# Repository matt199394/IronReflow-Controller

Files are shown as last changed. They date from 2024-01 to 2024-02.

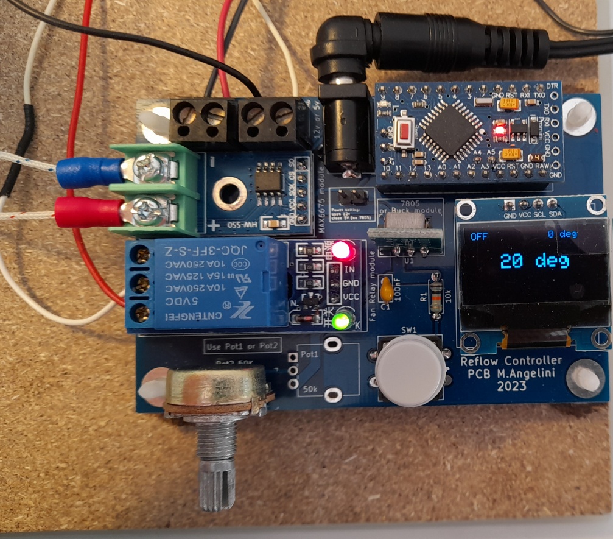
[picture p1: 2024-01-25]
assembled_pcb.jpg

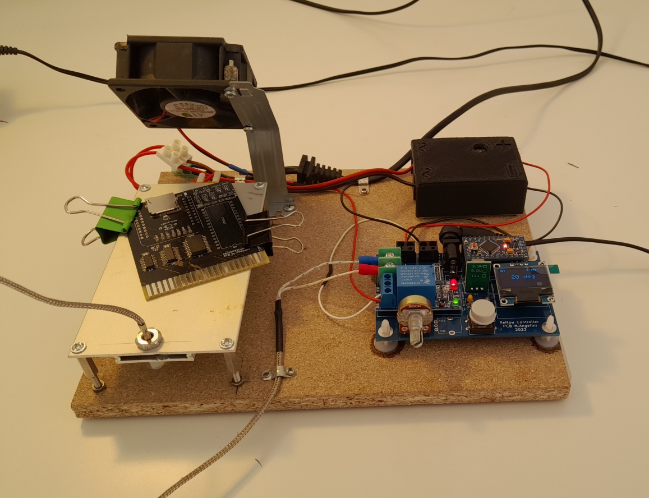
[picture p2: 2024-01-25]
final_result.jpg

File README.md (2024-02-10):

Iron Relow station Aka Soldering/Desoldering SMD Station

Brilliant project find on youtube at https://www.youtube.com/watch?v=2hhL1sXg254&t=1831s
I have made my custom PCB. 
You have to set some #DEFINE to set the heater time and fine tuning the proper temperature. You have to do some trial depending of solder paste and of iron plate caracteristics.
In my case I have use a chaep heating plate and 138°C lead free paste.
Works very well and I'm pretty ststisfied!
Thanks to Davide Gatti for the video and code!
Video demo: https://www.youtube.com/watch?v=i8gFOUQswV8
assembled_pcb
final_result

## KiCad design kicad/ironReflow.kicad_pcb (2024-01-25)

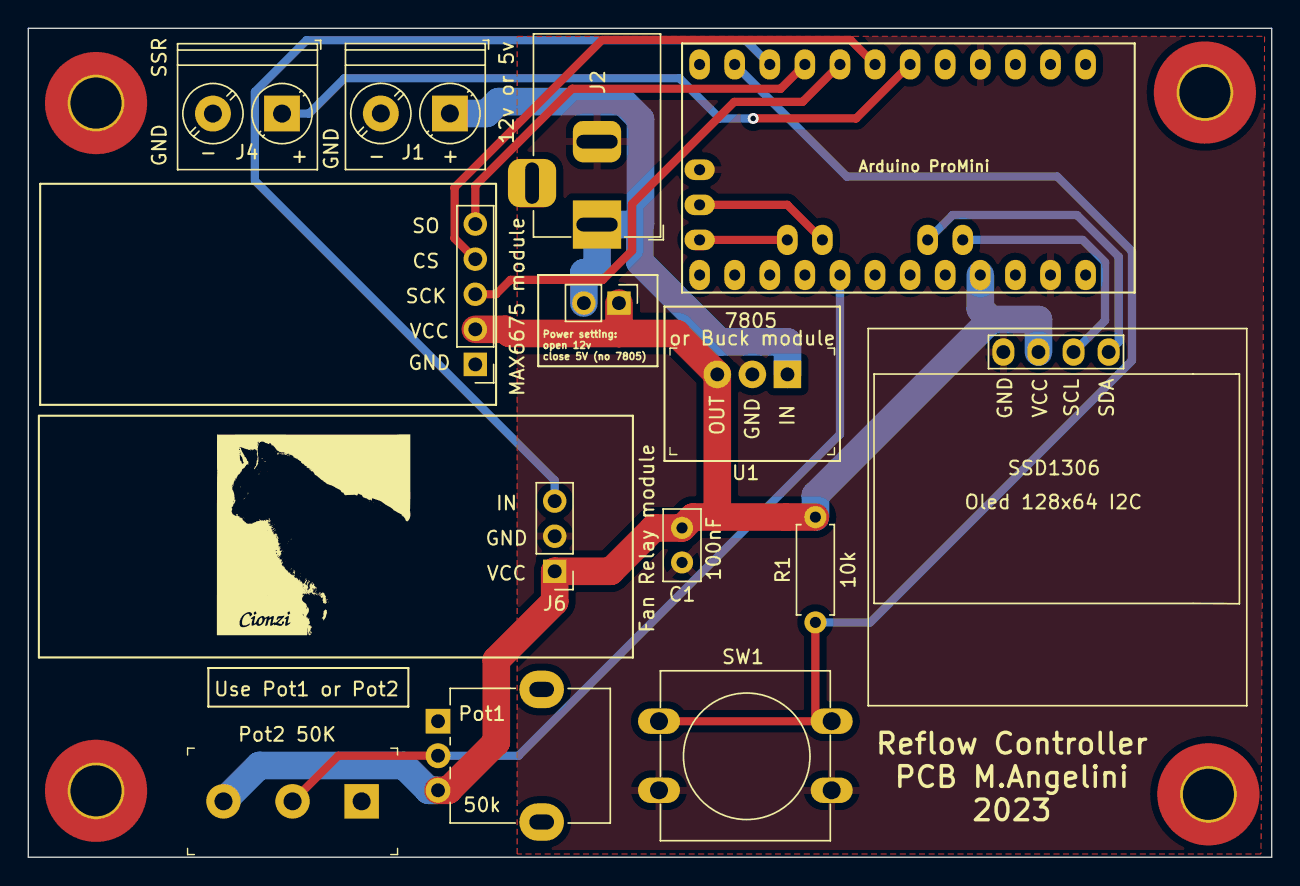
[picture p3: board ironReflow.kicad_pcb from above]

Board: 2 copper layers, 90.0 x 60.0 mm, 19 parts (0 on the bottom side), 12 nets.

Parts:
 : LOGO; cionzi
Arduino ProMini: ArduinoProMini; pro_mini
C1: 100nF; C_Disc_D5.0mm_W2.5mm_P2.50mm
H1, H2, H3, H4: MountingHole; MountingHole_3.7mm_Pad_TopBottom
J1: 12v or 5v; TerminalBlock_Phoenix_PT-1,5-2-5.0-H_1x02_P5.00mm_Horizontal
J2: Conn_Coaxial_Power; BarrelJack_Horizontal
J3: Conn_01x02_Male; PinHeader_1x02_P2.54mm_Vertical
J4: SSR; TerminalBlock_Phoenix_PT-1,5-2-5.0-H_1x02_P5.00mm_Horizontal
J5: MAX6675 module; PinHeader_1x05_P2.54mm_Vertical
J6: Fan Relay module; PinHeader_1x03_P2.54mm_Vertical
J7: Pot2 50K; Term_Block_1x3_P5mm
Oled 128x64 I2C: SSD1306; 128x64OLED_I2C
Pot1: 50k; Potentiometer_Alpha_RD901F-40-00D_Single_Vertical
R1: 10k; R_Axial_DIN0207_L6.3mm_D2.5mm_P7.62mm_Horizontal
SW1: SW_Push; SW_PUSH-12mm
U1: 7805; 3-SIP_Module_V7805-500

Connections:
+5V: Arduino ProMini.21 (VCC), C1.1, J3.1, J5.2, J6.1, J7.3, Oled 128x64 I2C.2 (VCC), Pot1.3, R1.2, U1.3 (Vo+)
+12V: J1.1, J2.1 (In), J3.2, U1.1 (Vin+)
GND: Arduino ProMini.4 (GND), Arduino ProMini.23 (GND), Arduino ProMini.29 (GND), C1.2, J1.2, J2.2 (Ext), J4.2, J5.1, J6.2, J7.1, Oled 128x64 I2C.1 (GND), Pot1.1, SW1.2, U1.2 (GND)
unnamed: Arduino ProMini.26 ((PCINT13/SCL/ADC5)PC5/19/A5), Oled 128x64 I2C.3 (SCL)
unnamed: Arduino ProMini.25 ((PCINT12/SDA/ADC4)PC4/18/A4), Oled 128x64 I2C.4 (SDA)
unnamed: Arduino ProMini.6 ((PCINT19/OC2B/INT1/PWM)PD3/3), J4.1
unnamed: Arduino ProMini.7 ((PCINT20/XCK/T0)PD4/4), J5.4
unnamed: Arduino ProMini.8 ((PCINT21/OC0B/T1/PWM)PD5/5), J5.3
unnamed: Arduino ProMini.9 ((PCINT22/OC0A/AIN0/PWM)PD6/6), J5.5
unnamed: Arduino ProMini.10 ((PCINT23/AIN1)PD7/7), J6.3
unnamed: Arduino ProMini.11 ((PCINT0/CLKO/ICP1)PB0/8), R1.1, SW1.1
unnamed: Arduino ProMini.17 ((PCINT8/ADC0)PC0/14/A0), J7.2, Pot1.2

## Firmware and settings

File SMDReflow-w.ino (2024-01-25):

#include <SPI.h>
#include <Wire.h>
#include <Adafruit_GFX.h>
#include <Adafruit_SSD1306.h>
#include "max6675.h"
//#include <Thermocouple.h>
//#include <MAX6675_Thermocouple.h>
 

#define PREHEAT_TIME 60   // Time heater ON needed to preheat to 150°
#define PREHEAT_WAIT 27   // Time heater OFF needed to reach preheat temp 150°
#define REFLOW_TIME 40    // Time heater ON to up temp to reflow temp (POT)
#define REFLOW_WAIT 16    // Time heater OFF needed to reach reflow temp (POT)
#define COOLDOWN_TIME 250 // Time heater OFF and FAN ON to cool heater

#define OLED_RESET 0  // GPIO0
#define SCREEN_WIDTH 128 // OLED display width, in pixels
#define SCREEN_HEIGHT 64 // OLED display height, in pixels
Adafruit_SSD1306 display(SCREEN_WIDTH, SCREEN_HEIGHT, &Wire, OLED_RESET);

int thermoDO = 6;  //SO
int thermoCS = 4;  // CS
int thermoCLK = 5; // SCK

//#define SCK_PIN   6  //  SCK
//#define SO_PIN    4  //  SO
//#define CS_PIN    5  //  CS

MAX6675 thermocouple(thermoCLK, thermoCS, thermoDO);
//Thermocouple* thermocouple;

const int button = 8;
const int solidstate = 3;
const int poti = A0;
const int fan = 7; 

const int temp_preheat = 150;
const int temp_reflow = 240;

int tread =0;
int temp_now = 0;
int temp_next = 0;
int temp_poti = 0;
int temp_poti_old = 0;
String state[] = {"OFF", "PREHEAT", "RAMP", "REFLOW", "REFLOW-W", "COOLING"};
int state_now = 0;

int time_count = 0;
int perc = 0;

int offset = 0;


void setup() {
  Serial.begin(9600);
  //thermocouple = new MAX6675_Thermocouple(SCK_PIN, CS_PIN, SO_PIN);

  pinMode(button, INPUT);
  pinMode(solidstate, OUTPUT);
  pinMode(fan, OUTPUT);
  digitalWrite(solidstate, LOW);
  digitalWrite(fan, LOW);
  display.begin(SSD1306_SWITCHCAPVCC, 0x3C);

  display.fillScreen(BLACK);
  display.setTextColor(WHITE);
  display.setTextSize(2);
  display.setCursor(18,0);
  display.println("SMD IRON");
  display.setCursor(20,20);
  display.println("REFLOW");
  //display.setTextSize(1);
  display.setCursor(20,40);
  display.println("STATION");
  display.display();
  delay(3000);
  display.clearDisplay();
  display.display();
 }

long t = millis();
long t_solder = millis();
long t_cool = millis();

void loop() {
  tread++;
  if (tread > 4) {
    temp_now = thermocouple.readCelsius();
    tread=0;
    Serial.print("temp:");
    Serial.println(temp_now);
  }
  
//  temp_now = thermocouple->readCelsius();
  
  temp_poti = map(analogRead(poti), 1023, 0, temp_preheat, temp_reflow);

  if (temp_poti != temp_poti_old) {
    int v = 0;
    display.fillScreen(WHITE);
    display.setTextColor(BLACK);
    display.setTextSize(1);
    display.setCursor(X(1, 7), Y(1, 0.1));
    display.println("PREHEAT");
    display.setTextSize(2);
    display.setCursor(X(2, 3), Y(2, 0.5));

    while (v < 100) {
      temp_poti = map(analogRead(poti), 1023, 0, temp_preheat, temp_reflow);
      if (temp_poti > temp_poti_old + 1 || temp_poti < temp_poti_old - 1) {
        display.fillScreen(WHITE);
        display.setTextSize(1);
        display.setCursor(X(1, 6), Y(1, 0.1));
        display.println("REFLOW");
        display.setTextSize(2);
        display.setCursor(X(2, 3), Y(2, 0.5));
        display.println(String(temp_poti));
        display.display();
        temp_poti_old = temp_poti;
        v = 0;
      }
      v++;
      delay(20);
    }
    temp_poti_old = temp_poti;
  }

  if (millis() > t + 200 || millis() < t) {
    PrintScreen(state[state_now], temp_next, temp_now, time_count, perc);
    t = millis();
  }


  if (digitalRead(button) == 0) {
    delay(100);
    int c = 0;
    while (digitalRead(button) == 0) {
      c++;
      if (c > 150) {
        digitalWrite(solidstate, LOW);
        state_now = 0;
        display.fillScreen(WHITE);
        display.setTextColor(BLACK);
        display.setTextSize(2);
        display.setCursor(X(2, 3), Y(2, 0.5));
        display.println("OFF");
        display.display();
        while (digitalRead(button) == 0) delay(1);
        return;
      }
      delay(10);
    }

    t_solder = millis();
    perc = 0,
    state_now++;
    if (state_now == 0) temp_next = 0;
    else if (state_now == 6) {
      state_now = 0;
      temp_next = 0;
    }
  }


  if (state_now == 1) { //PREHEAT
    temp_next = temp_preheat;
    regulate_temp(temp_now, temp_preheat);
    perc = int((float(temp_now) / float(temp_preheat)) * 100.00);
    time_count = ((t_solder/10)  + PREHEAT_TIME * 100 - (millis()/10)) / 100;
    if (time_count <= 0 || perc >= 100) {
      t_solder = millis();
      state_now = 2;
    }
  }
  else if (state_now == 2) { //PREHEAT WAIT
    temp_next = temp_preheat;
    perc = int((float(temp_now) / float(temp_preheat)) * 100.00);
    time_count = ((t_solder/10)  + PREHEAT_WAIT * 100 - (millis()/10)) / 100;
    digitalWrite(solidstate, LOW);
    if (time_count <= 0 || perc >= 100) {
      t_solder = millis();
      state_now = 3;
    }  
  }
  else if (state_now == 3) { //REFLOW
    temp_next = temp_poti ;
    regulate_temp(temp_now, temp_poti);
    perc = int((float(temp_now) / float(temp_poti)) * 100.00);
    time_count = ((t_solder/10)  + REFLOW_TIME * 100 - (millis()/10)) / 100;
    if (time_count <= 0 || perc >= 100) {
      state_now = 4;
      t_solder = millis();
    }
  }

  else if (state_now == 4) { //REFLAW WAIT
    temp_next = temp_poti ;
    perc = int((float(temp_now) / float(temp_poti)) * 100.00);
    time_count = ((t_solder/10)  + REFLOW_WAIT * 100 - (millis()/10)) / 100;
    digitalWrite(solidstate, LOW);
    if (time_count <= 0 || perc >= 100) {
      t_solder = millis();
      state_now = 5;
      perc = 0;
    }  
  }
  
  
  else if (state_now == 5) { //COOLING
    temp_next = 0;
    digitalWrite(solidstate, LOW);
    digitalWrite(fan, HIGH);

    time_count = ((t_solder/10)  + COOLDOWN_TIME * 100 - (millis()/10)) / 100;
    
    if (time_count <= 0) {
      state_now = 0;
      digitalWrite(fan, LOW);
    }
  }
  else {
    digitalWrite(solidstate, LOW);
    digitalWrite(fan, LOW);
    time_count = 0;
  }

  delay(30);
}




void regulate_temp(int temp, int should) {
  if (should <= temp - offset) {
    digitalWrite(solidstate, LOW);
  }
  else if (should > temp + offset) {
    digitalWrite(solidstate, HIGH);
  }
}


void PrintScreen(String state, int soll_temp, int ist_temp, int tim, int percentage) {
  display.clearDisplay();
  display.setTextColor(WHITE);
  display.setTextSize(1);
  display.setCursor(0, 0);
  display.println(state);

  display.setCursor(80, 0);
  String str = String(soll_temp) + " deg";
  display.println(str);

  if (tim != 0) {
    display.setCursor(0, 50);
    str = String(tim) + " sec";
    display.println(str);
  }
  
  if (percentage != 0) {
    display.setCursor(80, 50);
    str = String(percentage) + " %";
    display.println(str);
  }

  display.setTextSize(2);
  display.setCursor(30, 22);
  str = String(ist_temp) + " deg";
  display.println(str);

  display.display();
}


int X(int textgroesse, int n) {
  //gibt die X koordinate aus, damit text mit n zeichen mittig ist

  return (0.5 * (display.width() - textgroesse * (6 * n - 1)));
}//end int X

int Y(int textgroesse, float f) {
  //gibt die Y koordinate aus, damit text mittig ist

  return (f * display.height() - (textgroesse * 4));
}//end int Y
